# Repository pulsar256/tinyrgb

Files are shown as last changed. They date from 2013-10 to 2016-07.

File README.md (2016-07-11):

TinyRGB
=======

##Abstract

TinyRGB is a small learning project of mine. The goal is to replace / provide remote controlled drivers of
RGB strips by a small Bluetooth-Enabled controller and driver.

##Design Considerations
The board layout has been restricted to 5x5cm so you can get your PCBs produced for instance by Seeedstudio for
very little investment. The ATTiny4313 microcontroller has been chosen with the Arduino-Community in mind. While
this chip is not compatible with your Arduino-IDE per se, it is very closely related to it and should make it
a little bit more accessible. The HC-05 Bluetooth module used is one of the most popular ones across the
maker/hacker communities and can be sourced for few Dollar/Euro from eBay.

##Protocol Specification

The TinyRGB Firmware supports 4 basic modes:

- Random RGB Fade Mode
- RGB Flasher Mode
- HSL Fader Mode
- Fixed RGB Mode

The modes can be configured using a simple and compact serial protocol which makes some sacrifices
in order to maintain "human" compatibility while being designed to be remote controlled by a rich
GUI application.

The implementation supports the following commands sent via a serial modem link (8 9600 8n1 None):
```
"SRGB:RRRGGGBBB"      set R/G/B values, implicit change to mode 001 - fixed RGB/HSL.
"SW:WWW"              set white level (unsupported by the current hardware)
"SO:±RR±GG±BB"        set offset R/G/B values for RGB Fade Mode (+/-99)
"SM:RRRGGGBBB"        set maximum R/G/B values for RGB Fade Mode
"SHSL:HHHSSSLL"       set the H/S/L values. Pass -01 to ignore a value.
"SMD:MMM"             set mode:
                       001 - fixed RGB/HSL
                       002 - random RGB fader
                       003 - HSL fader
                       004 - RGB Flasher
"SD:DDD"              set delay for fade / flash modes.
"SAV:VVV"             enables (VVV > 0) or disables (VVV == 0) the eeprom autosave function.
"status"              get current RGB values and mode
"help"                help screen.
```

Setting HSL values does not put the controller into a fixed color mode. If you want to tweak partial HSL registers
while the colorcycling is active, you can pass a negative value to any color component to ignore it. For example
adjusting the saturation while not disturbing the hue position can be executed as: "SHSL:-01128-01"

If you want to implement a continuous color cycling or other effects on the controller side, disabling the eeprom
(via "SAV:000") is highly recommended to prevent the eeprom wearing. This mode is not persistent.

RGB offsets and maximum caps only apply to mode 002 (RGB Fader)

##Current Status
###Hardware

The hardware can be considered to be beta at best. Changes to be considered for a new HW revision:

- [ ] 7805 regulator needs to be Rotated by 180° to prevent issues with heatsink mounting
- [ ] Better decoupling
- [ ] Bump up the PCB size to 5x10cm to enable the hardware changes below.
- [ ] Use a 16MHz quartz instead of 20 to improve compatibility with standard UART baudrates.
- [ ] Hook up HC05 pin 34 to the AVR to enable the AT Mode.
- [ ] needs verification: hook up HC05 Reset line to the AVR to exit the AT mode. If powercycling is required, use a transitor to control the VCC line.
- [ ] Optional: status LEDS for the HC-05 module (pin 31, pin 32)
- [ ] Use 4  mosfets instead of the ULN2003 transistor array to drive loads > 1A per channel enabling the 4th white channel found on some RGB+W strips.
- [ ] TBD: Use the PCB as a heatsink for the 7805, alternatively put the regulator to one side of the PCB so it can be bend in a 90° angle and attach a dedicated heatsink "offboard".
- [ ] Use higher resistor values for the status and power leds to save ~15-20 mA

Please note, that the BT HC05 module will consume about 50mA current while in pairing mode and about 8mA
(according th the data sheet http://www.exp-tech.de/service/datasheet/HC-Serial-Bluetooth-Products.pdf)
while paired. This needs to be verified, the whole system will consume upto 45mA in idle (status LED lit)
and 70mA while paired.

###Firmware

The firmware controls the RGB channels via PWM and stores its last state in the eeprom to retain
its settings on a power cycle. See the protocol specification for further details on implemented
features and modes.

Open issues:

- [ ] Provide a unix makefile and integration with avrdude
- [ ] try to improve power consumption in pairing mode, 7805 regulator will be running quite hot otherwise.
- [ ] change the HC-05 BT Module name to TinyRGB on first boot. (hardware fix required)

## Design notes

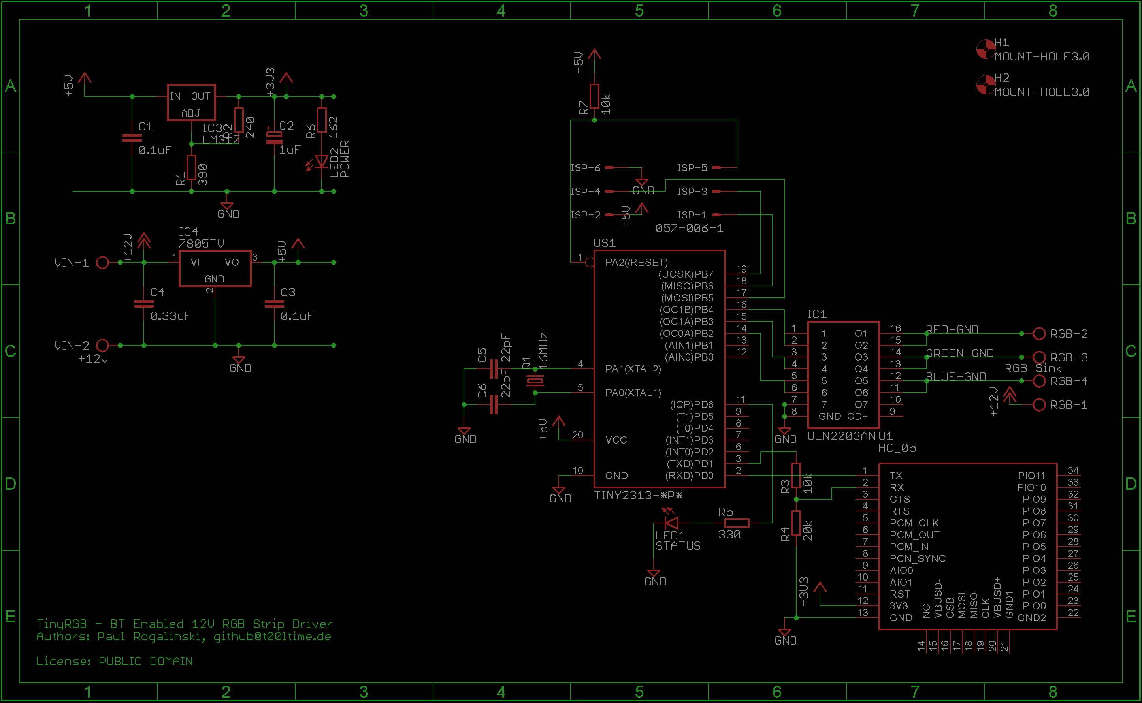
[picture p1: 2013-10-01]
schematic.png

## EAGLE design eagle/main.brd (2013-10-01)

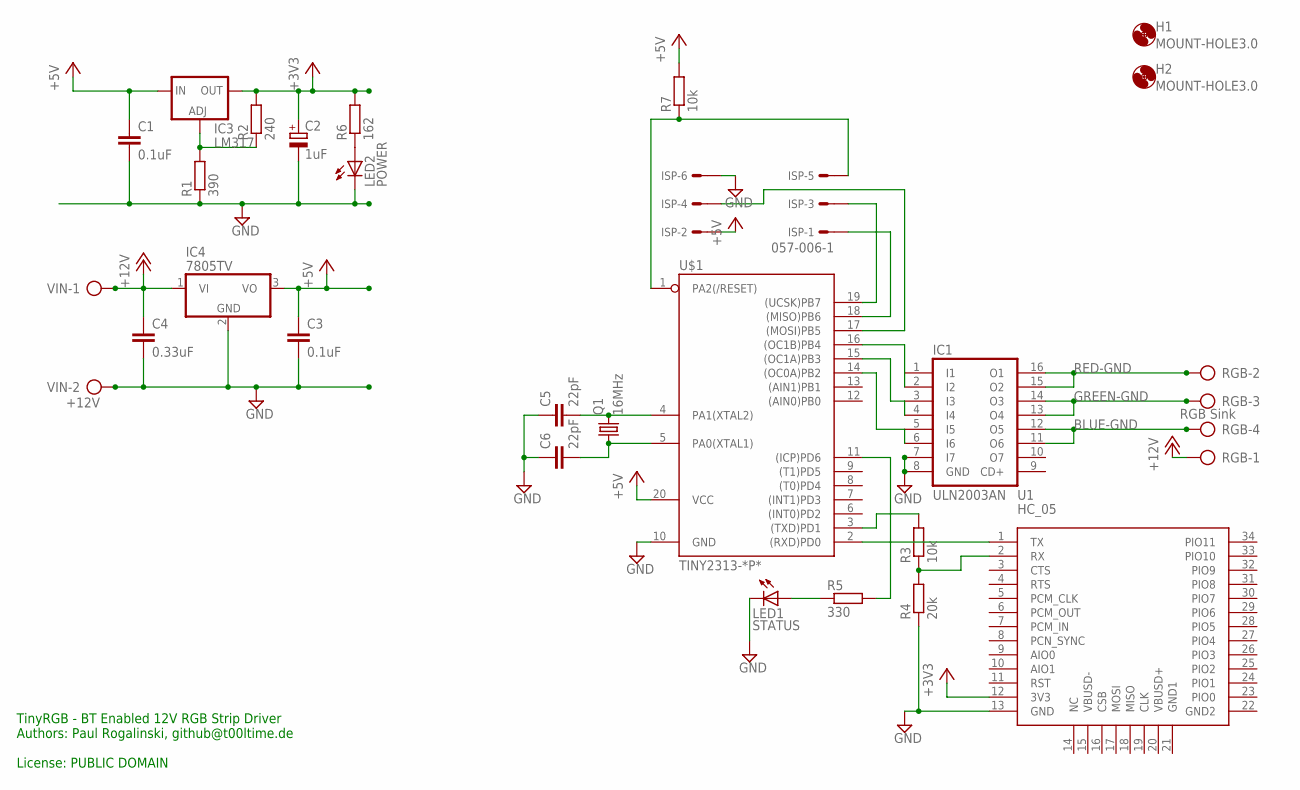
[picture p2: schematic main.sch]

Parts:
C1, C3: 0.1uF; C025-025X050
C2: 1uF; E2-5
C4: 0.33uF; C025_050-025X075
C5, C6: 22pF; C025-024X044
H1, H2: MOUNT-HOLE3.0; 3,0
IC1: ULN2003AN; DIL16
IC3: LM317; 317L
IC4: 7805TV; TO220V
ISP: 057-006-1
LED1: STATUS; LED3MM
LED2: POWER; LED3MM
Q1: 16MHz; HC49U-V
R1: 390; 0207/5V
R2: 240; 0207/5V
R3, R7: 10k; 0207/5V
R4: 20k; 0207/5V
R5: 330; 0207/5V
R6: 162; 0207/5V
RGB: RGB Sink; AK500/4
U1: HC_05; BLUETOOTH_SMD
U$1: TINY2313-*P*; DIL20
VIN: +12V; AK500/2

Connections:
+3V3: C2.+, IC3.2 (OUT), R2.2, R6.2, U1.12 (3V3)
+5V: C1.1, C3.1, IC3.3 (IN), IC4.3 (VO), ISP.2, R7.2, U$1.20 (VCC)
+12V: C4.1, IC4.1 (VI), RGB.1, VIN.1
BLUE-GND: IC1.11 (O6), IC1.12 (O5), RGB.4
GND: C1.2, C2.-, C3.2, C4.2, C5.1, C6.1, IC1.7 (I7), IC1.8 (GND), IC4.2 (GND), ISP.6, LED1.K (C), LED2.K (C), R1.1, R4.1, U1.13 (GND), U$1.10 (GND), VIN.2
GREEN-GND: IC1.13 (O4), IC1.14 (O3), RGB.3
unnamed: R3.2, U$1.3 ((TXD)PD1)
unnamed: U1.1 (TX), U$1.2 ((RXD)PD0)
unnamed: IC3.1 (ADJ), R1.2, R2.1
unnamed: IC1.1 (I1), IC1.2 (I2), U$1.16 ((OC1B)PB4)
unnamed: IC1.3 (I3), IC1.4 (I4), U$1.15 ((OC1A)PB3)
unnamed: IC1.5 (I5), IC1.6 (I6), U$1.14 ((OC0A)PB2)
unnamed: C5.2, Q1.2, U$1.4 (PA1(XTAL2))
unnamed: C6.2, Q1.1, U$1.5 (PA0(XTAL1))
unnamed: ISP.1, U$1.18 ((MISO)PB6)
unnamed: R3.1, R4.2, U1.2 (RX)
unnamed: ISP.3, U$1.19 ((UCSK)PB7)
unnamed: ISP.4, U$1.17 ((MOSI)PB5)
unnamed: ISP.5, R7.1, U$1.1 (PA2(/RESET))
unnamed: LED1.A, R5.1
unnamed: LED2.A, R6.1
unnamed: R5.2, U$1.11 ((ICP)PD6)
RED-GND: IC1.15 (O2), IC1.16 (O1), RGB.2

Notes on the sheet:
TinyRGB - BT Enabled 12V RGB Strip Driver Authors: Paul Rogalinski, github@t00ltime.de License: PUBLIC DOMAIN

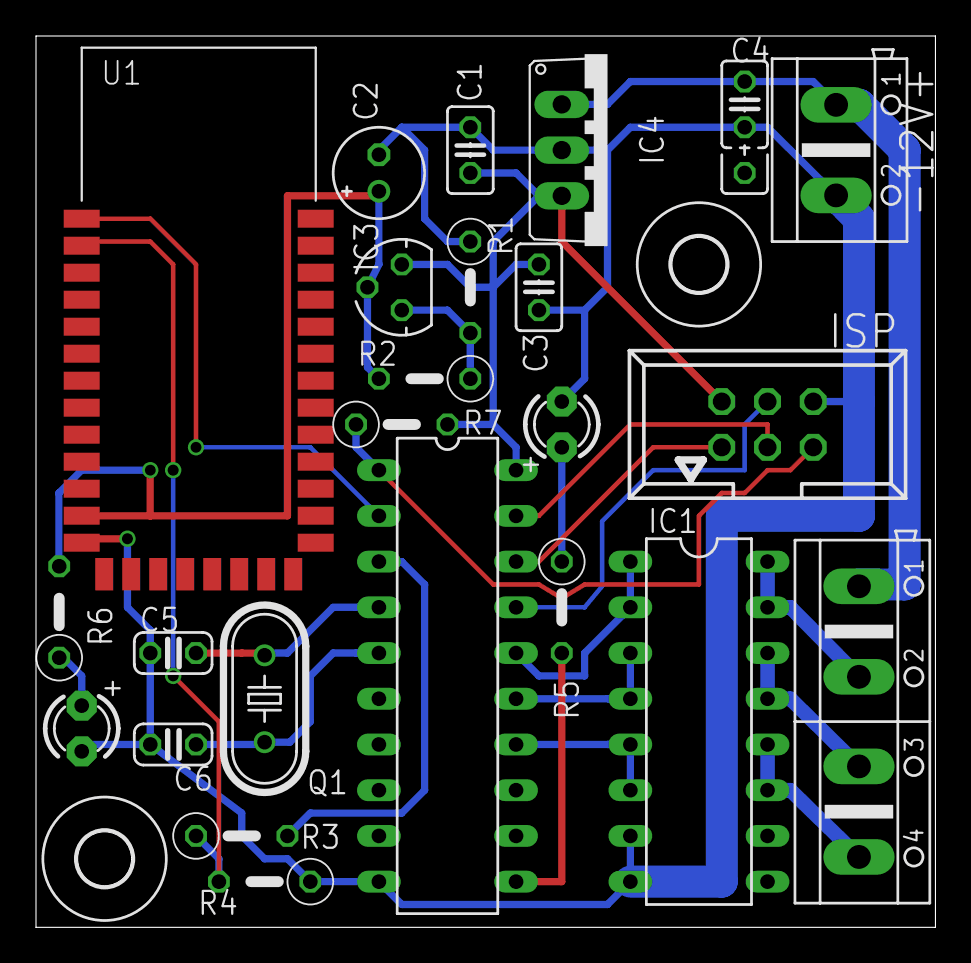
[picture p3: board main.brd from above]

Board: 4 copper layers, 50.0 x 49.5 mm, 26 parts (0 on the bottom side), 23 nets.

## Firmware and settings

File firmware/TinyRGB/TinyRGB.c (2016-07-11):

/*
* TinyRGB.c
*
* Created: 11.09.2013 20:10:35
* Author: Paul Rogalinski, paul@paul.vc
*
* Pins:
*  2: RX  -> BT TX
*  3: TX  -> BT RX
* 11: PD6 -> Status LED
* 14: PB2 / OC0A -> Blue
* 15: PB3 / OC1A -> Green
* 16: PB4 / OC1B -> RED
*  9: PD5 / OC0B -> White (unsupported by the current hardware design)
\o/
*/

#include "TinyRGB.h"

#include <avr/io.h>
#include <util/delay.h>
#include <avr/pgmspace.h>
#include <avr/interrupt.h>
#include <avr/eeprom.h>
#include <string.h>
#include <stdlib.h>

#include "random.h"
#include "pwm.h"
#include "usart.h"
#include "colors.h"

HslColor  hsl;   // current hsl values (in MODE_FADE_HSL)
RgbColor  oRgb;  // offset values for rgb, cast to int8_t before using
RgbColor  rgb;   // current rgb values (in MODE_FADE_RANDOM_RGB)
RgbColor  tRgb;  // target rgb values (for MODE_FADE_RANDOM_RGB)
RgbColor  mRgb;  // maximum / clipping values
uint8_t   white; // white level, unsupported by the current hardware

uint8_t mode = MODE_FADE_RANDOM_RGB;
int wait = 100;
int currentWait = 100;

bool autosaveEnabled = true;

/*
 * take a guess.
 */
void printHelp() {
	writePgmStringToSerial(PSTR("\f\aTiny RGB 0.1, github.com/pulsar256/tinyrgb \\r\nFull protocol specification available at Github.\r\nCompiled: " __TIMESTAMP__ "\r\n"));
}


/*
 * Parses an integer value from a triple of chars. advances the pointer to the string afterwards
 */
int parseNextInt(char** buffer) {
	char val[4];
	strncpy(val,*buffer,3);
	val[3]='\0';
	*buffer = *buffer + 3;
	return atoi(val);
}

/*
* dumps the contents of the RgbColor (or casted HslColor) structure to serial.
*/
void dumpRgbColorToSerial(RgbColor* color) {
	char buffer[4];
	itoa(color->r,buffer,10);
	writeStringToSerial(buffer);
	writeNewLine();
	itoa(color->g,buffer,10);
	writeStringToSerial(buffer);
	writeNewLine();
	itoa(color->b,buffer,10);
	writeStringToSerial(buffer);
	writeNewLine();
}


/*
 * Parses the command buffer and changes the current state accordingly.
 *
 * Command Syntax:
 * "SRGB:RRRGGGBBB"      set R/G/B values, implicit change to mode 001 - fixed RGB/HSL.
 * "SW:WWW"              set white level (unsupported by the current hardware)
 * "SO:±RR±GG±BB"        set offset R/G/B values for RGB Fade Mode (+/-99)
 * "SM:RRRGGGBBB"        set maximum R/G/B values for RGB Fade Mode
 * "SHSL:HHHSSSLL"       set the H/S/L values. Pass -01 to ignore a value.
 * "SMD:MMM"             set mode:
 *                        001 - fixed RGB/HSL
 *                        002 - random RGB fader
 *                        003 - HSL fader
 *                        004 - RGB Flasher
 * "SD:DDD"              set delay for fade / flash modes.
 * "SAV:VVV"             enables (VVV > 0) or disables (VVV == 0) the eeprom autosave function.
 * "status"              get current RGB values and mode
 * "help"                help screen.
 */
bool handleCommands(char* commandBuffer) {
	char *bufferCursor;
	
	// Set RGB values and switch to MODE_FIXED (001)
	bufferCursor = strstr( commandBuffer, "SRGB:" );
	if (bufferCursor != NULL) {
		mode = MODE_FIXED;
		bufferCursor += 5;
		rgb.r = parseNextInt(&bufferCursor);
		rgb.g = parseNextInt(&bufferCursor);
		rgb.b = parseNextInt(&bufferCursor);
		return true;
	}
	
	// Set max RGB
	bufferCursor  = strstr( commandBuffer, "SM:" );
	if (bufferCursor != NULL) {
		bufferCursor += 3;
		mRgb.r = parseNextInt(&bufferCursor);
		mRgb.g = parseNextInt(&bufferCursor);
		mRgb.b = parseNextInt(&bufferCursor);
		return true;
	}
	
	// Set RGB offset
	bufferCursor  = strstr( commandBuffer, "SO:" );
	if (bufferCursor != NULL) {
		bufferCursor += 3;
		oRgb.r  = parseNextInt(&bufferCursor);
		oRgb.g  = parseNextInt(&bufferCursor);
		oRgb.b  = parseNextInt(&bufferCursor);
		return true;
	}
	
	#ifdef ENABLE_WHITECHANNEL
		// Set white level (unsupported by current hardware design)
		bufferCursor  = strstr( commandBuffer, "SW:" );
		if (bufferCursor != NULL) {
			bufferCursor += 3;
			white = parseNextInt(&bufferCursor);
			return true;
		}
	#endif
	
	// set delay / wait cycles between color changes.
	bufferCursor  = strstr( commandBuffer, "SD:" );
	if (bufferCursor != NULL) {
		bufferCursor += 3;
		wait = parseNextInt(&bufferCursor);
		return true;
	}
	
	// Set HSL register values, values < 0 are ignored, 
	// mode is not changed to fixed to keep the colors
	// cycling while adjusting saturation or luminosity.
	bufferCursor  = strstr( commandBuffer, "SHSL:" );
	if (bufferCursor != NULL) {
		bufferCursor += 5;
		int tmp = 0;
		tmp = parseNextInt(&bufferCursor);
		if (tmp > 0) hsl.h = tmp;
		tmp = parseNextInt(&bufferCursor);
		if (tmp > 0) hsl.s = tmp;
		tmp = parseNextInt(&bufferCursor);
		if (tmp > 0) hsl.l = tmp;
		
		// we always use the rgb register to set the output PWM channels.
		// in order to use hsl in a fixed mode, we need to do the conversion
		// once here.
		hslToRgb(&hsl,&rgb);
		
		return true;
	}
	
	// Sets the delay
	bufferCursor  = strstr( commandBuffer, "SMD:" );
	if (bufferCursor != NULL) {
		bufferCursor += 4;
		mode = parseNextInt(&bufferCursor);
		return true;
	}
	
	// Dumps all status registers
	bufferCursor = strstr( commandBuffer, "status" );
	if (bufferCursor != NULL) {
		char buffer[4];
		
		writeNewLine();
		writePgmStringToSerial(PSTR("#Mode:"));
		writeNewLine();
		itoa(mode,buffer,10);
		writeStringToSerial(buffer);
		writeNewLine();
		
		writeNewLine();
		writePgmStringToSerial(PSTR("#Delay:"));
		writeNewLine();
		itoa(wait,buffer,10);
		writeStringToSerial(buffer);
		writeNewLine();
		
		writeNewLine();
		writePgmStringToSerial(PSTR("#Autosave:"));
		writeNewLine();
		if (autosaveEnabled) writePgmStringToSerial(PSTR("enabled"));
		else writePgmStringToSerial(PSTR("disabled"));
		writeNewLine();
		
		writeNewLine();
		writePgmStringToSerial(PSTR("#Current RGB Values:"));
		writeNewLine();
		dumpRgbColorToSerial(&rgb);
		
		writeNewLine();
		writePgmStringToSerial(PSTR("#Current HSL Values:"));
		writeNewLine();
		dumpRgbColorToSerial((struct RgbColor *)&hsl); // hsl has same memory layout as rgb
		
		writeNewLine();
		writePgmStringToSerial(PSTR("#Current RGB Offset Values:"));
		writeNewLine();
		dumpRgbColorToSerial(&oRgb);
		
		writeNewLine();
		writePgmStringToSerial(PSTR("#Current RGB Clipping Values:"));
		writeNewLine();
		dumpRgbColorToSerial(&mRgb);
		
		return true;
	}
	
	// Dumps all status registers
	bufferCursor = strstr( commandBuffer, "help" );
	if (bufferCursor != NULL) {
		printHelp();
		return true;
	}
	
	// Enables (value > 0) / Disables (value == 0) the autosave function.
	bufferCursor  = strstr( commandBuffer, "SAV:" );
	if (bufferCursor != NULL) {
		bufferCursor += 4;
		uint8_t value =  parseNextInt(&bufferCursor);
		if (value > 0) autosaveEnabled = true;
		else autosaveEnabled = false;
		return true;	
	}
	
	return false;	
}


/*
 * Callback for the USART handler, executed each time the buffer is full or a 
 * newline has been submitted.
 */
void serialBufferHandler(char* commandBuffer) {
	cli();
	
	if (!handleCommands(commandBuffer)) {
		writePgmStringToSerial(PSTR("\r\nERR\r\n"));
	}
	else {
		writePgmStringToSerial(PSTR("\r\nOK\r\n"));
		if(autosaveEnabled) updateEEProm();
	}
	
	#ifdef ENABLE_BLINK_CONFIRM
	// "roger-beep", very annoying if you do real time updates.
	setRgb(0,0,0);
	_delay_ms(10);
	setRgb(0,255,0);
	_delay_ms(100);
	setRgb(0,0,0);
	_delay_ms(10);
	#endif
	
	sei();
}


/*
 * writes an uint8 value into the eeprom at the offset position. 
 * the passed offset will be off set once again by the value of 
 * EEPStart
 */
void writeEepromByte(int offset, uint8_t value) {
	uint8_t* addr = (uint8_t*)(EEPStart + offset);
	eeprom_update_byte(addr,value);
}


/*
 * reads an uint8 value from the eeprom at the offset position. 
 * the passed offset will be off set once again by the value of 
 * EEPStart
 */
uint8_t readEepromByte(int offset) {
	uint8_t* addr = (uint8_t*)(EEPStart + offset);
	return eeprom_read_byte(addr);
}


/*
 * Saves current state into the eeprom
 */
void updateEEProm() {
	int c = 0;
	writeEepromByte(c++, mode);
	writeEepromByte(c++, rgb.r);
	writeEepromByte(c++, rgb.g);
	writeEepromByte(c++, rgb.b);
	writeEepromByte(c++, hsl.h);
	writeEepromByte(c++, hsl.s);
	writeEepromByte(c++, hsl.l);
	writeEepromByte(c++, oRgb.r);
	writeEepromByte(c++, oRgb.g);
	writeEepromByte(c++, oRgb.b);
	writeEepromByte(c++, wait);
	writeEepromByte(c++, mRgb.r);
	writeEepromByte(c++, mRgb.g);
	writeEepromByte(c++, mRgb.b);
	#ifdef ENABLE_WHITECHANNEL
	writeEepromByte(c++, white);
	#endif
}


/*
 * restores the current state from the eeprom 
 */
void restoreFromEEProm() {
	int c = 0;
	mode = readEepromByte(c++);
	mode=0;
	
	// eeprom uninitialized. 
	if (mode == 0)  {
		// this won't work in the current hardware revision.
		// it is necessary to pull the pin 34 high on the
		// BT module in order to enter the "AT-Mode". Furthermore
		// the module will expect a baud rate of 38400 which we 
		// cannot precisely generate using a 20MHz quartz. So even if
		// you manage to pull the line high and boot into this
		// part of code, the name change will fail due to a 1.4% error
		// in the baud rate.
		// next hw revision shall use a 16mhz quartz and 
		// be able to control the pin 34 on the BT module.
		//   
		// writeStringToSerial("AT+NAME=TinyRGB\r\n");
		return;
	}; 
	rgb.r = readEepromByte(c++);
	rgb.g = readEepromByte(c++);
	rgb.b = readEepromByte(c++);
	hsl.h = readEepromByte(c++);
	hsl.s = readEepromByte(c++);
	hsl.l = readEepromByte(c++);
	oRgb.r = readEepromByte(c++);
	oRgb.g = readEepromByte(c++);
	oRgb.b = readEepromByte(c++);
	wait = readEepromByte(c++);
	mRgb.r = readEepromByte(c++);
	mRgb.g = readEepromByte(c++);
	mRgb.b = readEepromByte(c++);
	#ifdef ENABLE_WHITECHANNEL
	white = readEepromByte(c++);
	#endif
}


/*
 * Initialization routines, self test and welcome screen. Main loop is implemented in the ISR below
 */
int main(void) {
	SLED_DDR = (1 << PIND6);

	initSerial();
	initPwm();
	restoreFromEEProm();
	
	setRgb(0,0,0);
	if (mode == 0) {
		mode = MODE_FADE_HSL;
		hsl.s = 254;
		hsl.l = 127;
		mRgb.r = 255;
		mRgb.g = 255;
		mRgb.b = 255;
	}	
	
	printHelp();
	setCommandBufferCallback(serialBufferHandler);
	
	// our "main" loop is scheduled by timer1's overflow IRQ
	// @20MHz system clock and a /64 timer pre-scaler the ISR will run at 610.3515625 Hz / every 1.639ms
	TIMSK |= (1 << TOIE1);
	sei();

	while(1);
}


/*
 * Scheduled to run every 1-2ms (depending on your system clock). Transfers the color values into
 * the PWM registers and, depending on the current mode, computes the colorcycling effects
 */
ISR(TIMER1_OVF_vect) {
	if (currentWait-- == 0) {
		currentWait = wait*10;
		if (mode == MODE_FADE_RANDOM_RGB) {
			if (tRgb.r == rgb.r) tRgb.r = getNextRandom(mRgb.r, (int8_t)oRgb.r, rgb.r);
			if (tRgb.g == rgb.g) tRgb.g = getNextRandom(mRgb.g, (int8_t)oRgb.g, rgb.g);
			if (tRgb.b == rgb.b) tRgb.b = getNextRandom(mRgb.b, (int8_t)oRgb.b, rgb.b);
			rgb.r += (rgb.r < tRgb.r) ? 1 : -1;
			rgb.g += (rgb.g < tRgb.g) ? 1 : -1;
			rgb.b += (rgb.b < tRgb.b) ? 1 : -1;
		}
		
		else if (mode == MODE_FADE_HSL) {
			hsl.h++;
			hslToRgb(&hsl,&rgb);
		}
		
		else if (mode == MODE_RANDOM_FLASH) {
			rgb.r = getNextRandom(mRgb.r, (int8_t)oRgb.r, rgb.r);
			rgb.g = getNextRandom(mRgb.g, (int8_t)oRgb.g, rgb.g);
			rgb.b = getNextRandom(mRgb.b, (int8_t)oRgb.b, rgb.b);
		}
		
		setRgb(rgb.r,rgb.g,rgb.b);				
		#ifdef ENABLE_WHITECHANNEL
		setWhite(white);
		#endif
		SLED_PORT ^= (1<<SLED_PIN);
	}
}

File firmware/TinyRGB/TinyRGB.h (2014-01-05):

/*
* TinyRGB.h
*
* Created: 03.01.2014 02:34:44
* Author: Paul Rogalinski, paul@paul.vc
*/


#ifndef TINYRGB_H_
#define TINYRGB_H_

#ifndef F_CPU
#define F_CPU 20000000UL     /* Set your clock speed here, mine is a 20 Mhz quartz*/
#endif


#define SLED_PORT               PORTD
#define SLED_DDR                DDRD
#define SLED_PIN                PIND6
#define REG_RED                 OCR1B
#define REG_GRN                 OCR1A
#define REG_BLU                 OCR0A
#define REG_WHI                 OCR0B
#define MODE_FIXED              1
#define MODE_FADE_RANDOM_RGB    2
#define MODE_FADE_HSL           3
#define MODE_RANDOM_FLASH       4
#define LOCAL_ECHO              1
//#define ENABLE_BLINK_CONFIRM
//#define ENABLE_WHITECHANNEL
#define	EEPStart                0x10


int parseNextInt(char** buffer);
void updateEEProm();
void restoreFromEEProm();
void serialBufferHandler(char* commandBuffer);

#endif /* TINYRGB_H_ */

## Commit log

2013-10-01 initial import
    [main.brd, main.sch]
2013-10-01 schematic image
2014-01-03 - added support for a dedicated white channel (not supported by the current hardware) - work in progress: command parser.
2014-01-03 Various bugfixes in mRgb/oRgb handling.
    [TinyRGB.c]
2014-01-03 Update TinyRGB.c
    autosaveEnabled was used to display it's state but was possibly not honoured when saving... possibly fixed now (no idea how to compile and test on mobile phone in github editor while being in the bathtub...)
    [TinyRGB.c]
2014-01-04 Code optimization & cosmetics
    - Removed dormant code
    - Fixed typos and formatting
    - completed documentation
    - Optimized for codesize
    [TinyRGB.c, TinyRGB.h]
2014-01-04 Fixed HSV Fader (now HSL)
    - replaced the HSV implementation with a HSL,
    adapted http://tog.acm.org/resources/GraphicsGems/gems/HSLtoRGB.c
    - Color-Conversion uses references now
    - Updated documentation
    [TinyRGB.c, TinyRGB.h]
2014-01-06 Slower transitions (x10)
    also made attempts to get into the command (AT) mode of the bt module.
    It turned out not to be possible using the current hardware revision.
